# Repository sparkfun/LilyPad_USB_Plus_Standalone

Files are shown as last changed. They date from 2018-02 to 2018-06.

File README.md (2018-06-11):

SparkFun LilyPad USB Plus
========================================

LilyPad USB Plus

[*LilyPad USB Plus (14631)*](https://www.sparkfun.com/products/14631)

This is the LilyPad USB Plus, a sewable electronics microcontroller board controlled by an ATmega32U4 with the Arduino bootloader. 

Repository Contents
-------------------

* **/Documentation** - Data sheets, additional product information
* **/Hardware** - Eagle design files (.brd, .sch)
* **/Production** - Production panel files (.brd)

<b>Note for Linux Users:</b> If you are installing the LilyPad USB Plus in Linux, this document has some specific notes:
<a href="https://github.com/sparkfun/LilyPad_ProtoSnap_Plus/blob/master/Documentation/LinuxInstallation.md">https://github.com/sparkfun/LilyPad_ProtoSnap_Plus/blob/master/Documentation/LinuxInstallation.md</a>.

Documentation
--------------
* **[Library](https://github.com/sparkfun/LilyPad_USB_Plus_Standalone/tree/master/Libraries)** - Arduino library for the LilyPad USB Plus.
* **[Hookup Guide](https://learn.sparkfun.com/tutorials/lilypad-usb-plus-hookup-guide)** - Basic hookup guide for the LilyPad USB Plus.

License Information
-------------------

This product is _**open source**_! 

Please review the LICENSE.md file for license information. 

If you have any questions or concerns on licensing, please contact techsupport@sparkfun.com.

Distributed as-is; no warranty is given.

- Your friends at SparkFun.

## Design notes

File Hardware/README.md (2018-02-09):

SparkFun <PRODUCT NAME> Design Files
=====================================

The .sch and .brd files hare are Eagle CAD schematic and PCB design files from SparkFun Electronics.
A freeware version of Eagle can be found [here](http://www.cadsoftusa.com/download-eagle/freeware/).

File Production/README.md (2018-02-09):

SparkFun <PRODUCT NAME> Production Files
=========================================

These are the production files SparkFun uses for printing PCBs.

License Information
-------------------
This product is open source! 

The hardware is released under [Creative Commons ShareAlike 4.0 International](https://creativecommons.org/licenses/by-sa/4.0/).

Please use, reuse, and modify these files as you see fit. Please maintain attribution to SparkFun Electronics and release anything derivative under the same license.

Distributed as-is; no warranty is given.

- Your friends at SparkFun.

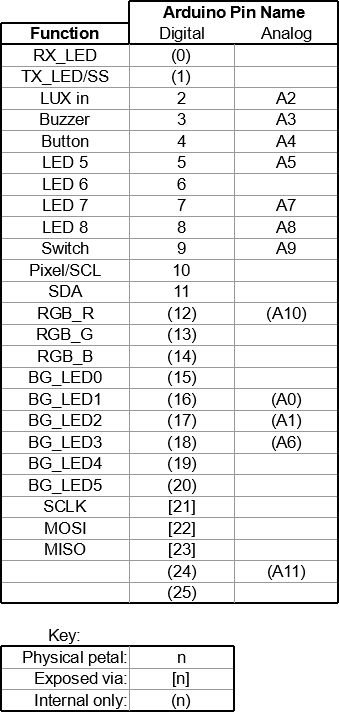
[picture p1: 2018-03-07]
Documentation/Lilypad_USB_Standalone_GPIO_Cheatsheet.png

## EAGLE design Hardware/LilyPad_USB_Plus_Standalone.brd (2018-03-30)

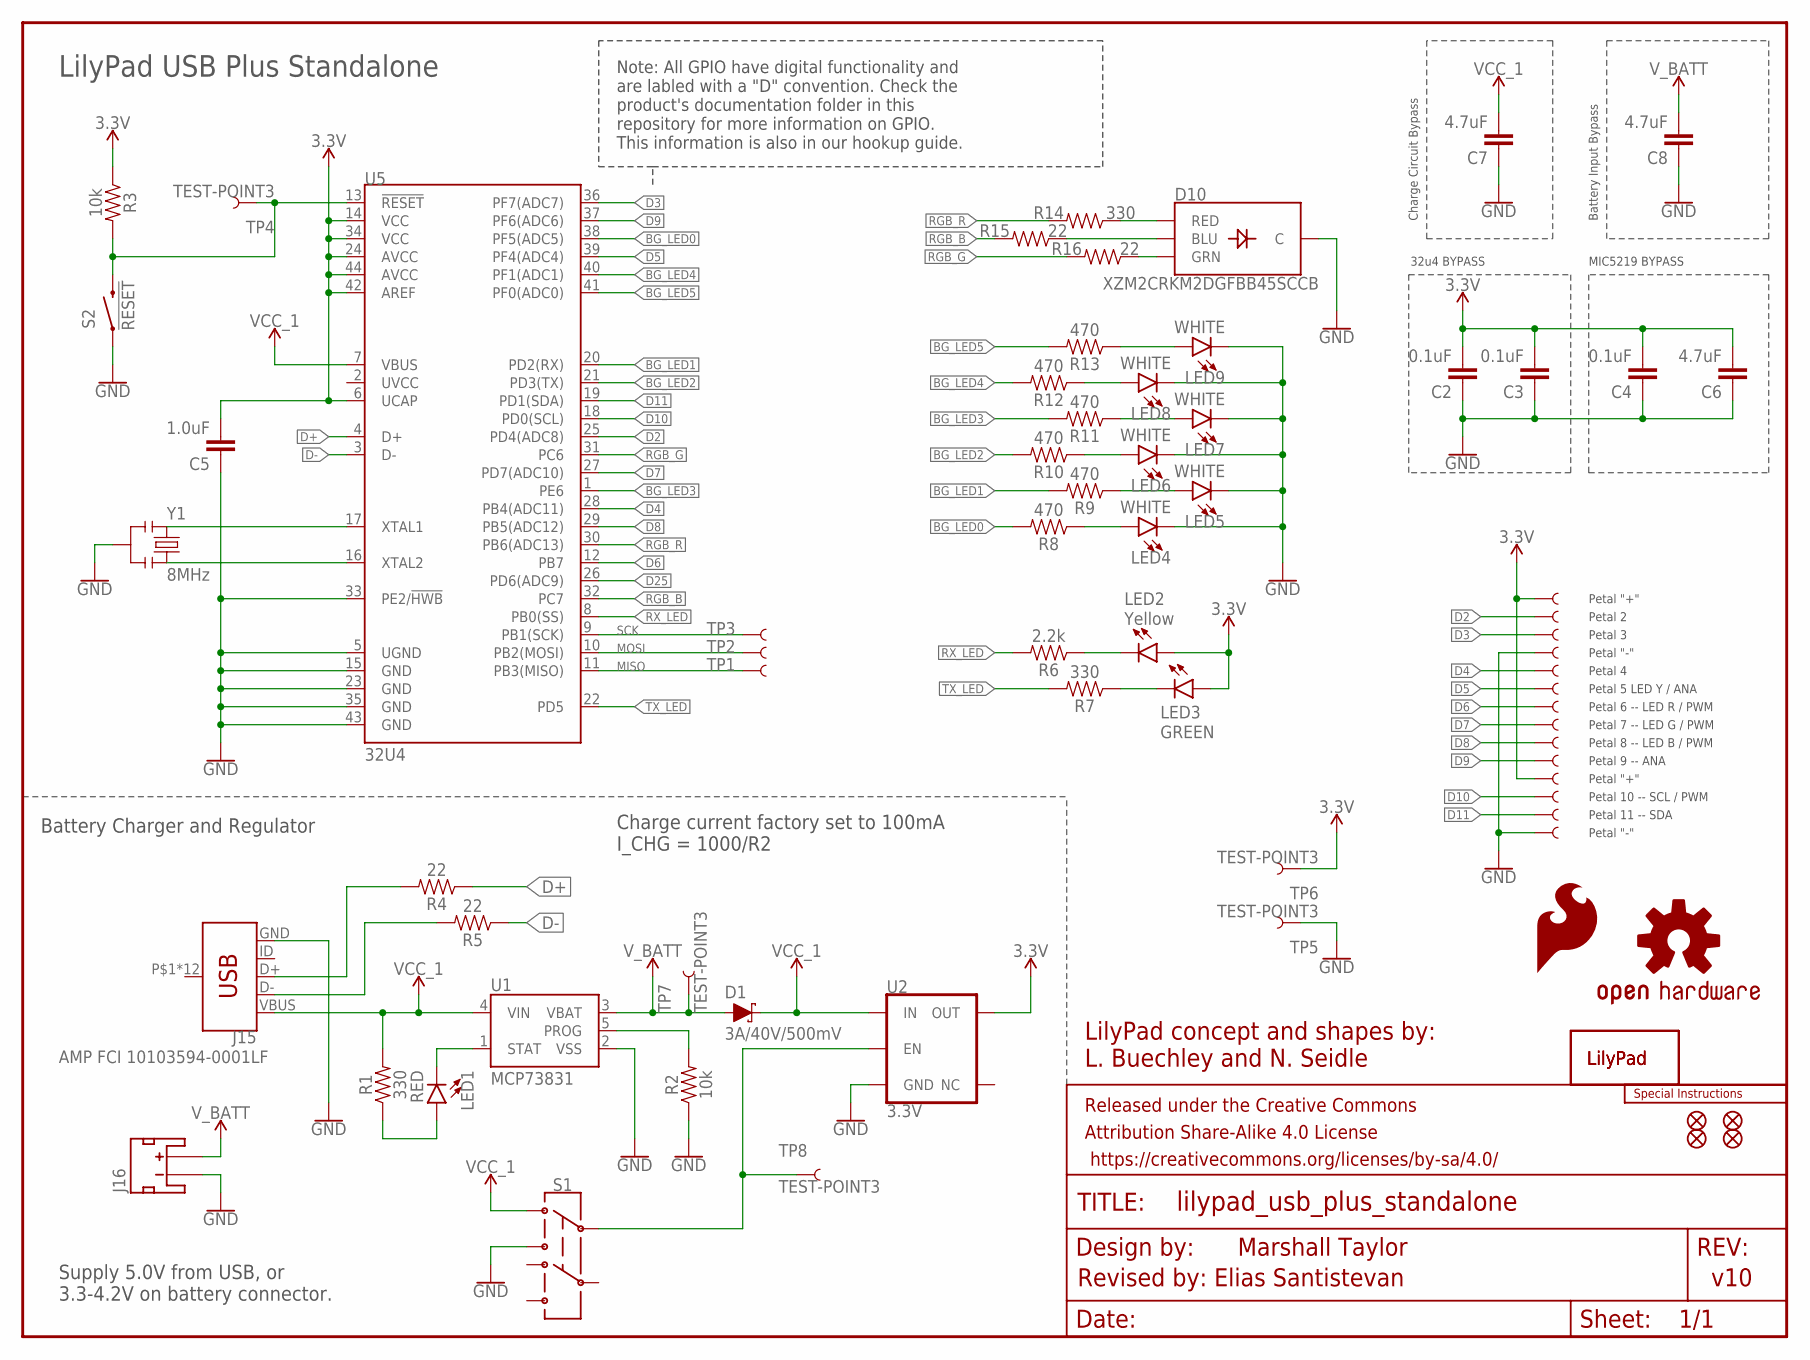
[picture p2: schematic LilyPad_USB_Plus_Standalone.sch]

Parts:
C2, C3, C4: 0.1uF; 0402
C5: 1.0uF; 0402
C6, C7, C8: 4.7uF; 0603
D1: 3A/40V/500mV; SMA-DIODE
D10: XZM2CRKM2DGFBB45SCCB; PLCC4SMDLED
FRAME1: FRAME-LETTER; CREATIVE_COMMONS
J1, J2, J3, J4, J5, J6, J7, J8, J9, J10, J11, J12, J13, J14: SEWTAP_LONG-2SIDE; PETAL-LONG-1-2SIDE
J15: AMP FCI 10103594-0001LF; USB-MICROB-PTH
J16: JST_2MM_MALE; JST-2-SMD
JP1, JP2, JP3, JP4: FIDUCIALUFIDUCIAL; MICRO-FIDUCIAL
LED1: RED; LED-0603
LED2: Yellow; LED-0603
LED3: GREEN; LED-0603
LED4, LED5, LED6, LED7, LED8, LED9: WHITE; LED-0603
LOGO1: SFE_LOGO_FLAME.2_INCH; SFE_LOGO_FLAME_.2
LOGO6: OSHW-LOGOS; OSHW-LOGO-S
R1, R7, R14: 330; 0603
R2, R3: 10k; 0603
R4, R5, R15, R16: 22; 0402
R6: 2.2k; 0603
R8, R9, R10, R11, R12, R13: 470; 0402
S1: SWITCH-DPDT-SMD-AYZ0202; SWITCH_DPDT_SMD_AYZ0202
S2: !RESET; TACTILE_SWITCH_SMD_5.2MM
TP1, TP2, TP3, TP4, TP5, TP6, TP7, TP8: TEST-POINT3; PAD.03X.03
U1: MCP73831; SOT23-5
U2: 3.3V; SOT23-5
U5: 32U4; QFN-44-PAD_1:1-LESS_PASTE
U$1, U$13: LILYLOGO_SHORT; LILYPAD-WEARABLES_LOGO-LILYPAD
U$44: SPECIAL_INSTRUCTIONS-ORDERING; ORDERING_INSTRUCTIONS
Y1: 8MHz; RESONATOR-SMD

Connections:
3.3V: C2.2, C3.2, C4.2, C5.2, C6.2, J1.1, J11.1, LED2.A, LED3.A, R3.1, TP6.P$1, U2.5 (OUT), U5.6 (UCAP), U5.14 (VCC), U5.24 (AVCC), U5.34 (VCC), U5.42 (AREF), U5.44 (AVCC)
BG_LED0: R8.2, U5.38 (PF5(ADC5))
BG_LED1: R9.2, U5.20 (PD2(RX))
BG_LED2: R10.2, U5.21 (PD3(TX))
BG_LED3: R11.2, U5.1 (PE6)
BG_LED4: R12.2, U5.40 (PF1(ADC1))
BG_LED5: R13.2, U5.41 (PF0(ADC0))
D2: J2.1, U5.25 (PD4(ADC8))
D3: J3.1, U5.36 (PF7(ADC7))
D4: J5.1, U5.28 (PB4(ADC11))
D5: J6.1, U5.39 (PF4(ADC4))
D6: J7.1, U5.12 (PB7)
D7: J8.1, U5.27 (PD7(ADC10))
D8: J9.1, U5.29 (PB5(ADC12))
D9: J10.1, U5.37 (PF6(ADC6))
D10: J12.1, U5.18 (PD0(SCL))
D11: J13.1, U5.19 (PD1(SDA))
D25: U5.26 (PD6(ADC9))
D+: R4.1, U5.4 (D+)
D-: R5.1, U5.3 (D-)
GND: C2.1, C3.1, C4.1, C5.1, C6.1, C7.1, C8.1, D10.4 (C), J4.1, J14.1, J15.GND, J16.1 (-), LED4.C, LED5.C, LED6.C, LED7.C, LED8.C, LED9.C, R2.1, S1.3, S2.1, S2.2 (1), TP5.P$1, U1.2 (VSS), U2.2 (GND), U5.5 (UGND), U5.15 (GND), U5.23 (GND), U5.33 (PE2/!HWB), U5.35 (GND), U5.43 (GND), Y1.2
MISO: TP1.P$1, U5.11 (PB3(MISO))
MOSI: TP2.P$1, U5.10 (PB2(MOSI))
unnamed: LED2.C, R6.1
unnamed: S1.2, TP8.P$1, U2.3 (EN)
unnamed: LED1.A, R1.1
unnamed: LED1.C, U1.1 (STAT)
unnamed: U5.17 (XTAL1), Y1.1
unnamed: R2.2, U1.5 (PROG)
unnamed: U5.16 (XTAL2), Y1.3
unnamed: D10.2 (GRN), R16.1
unnamed: LED7.A, R11.1
unnamed: LED6.A, R10.1
unnamed: LED5.A, R9.1
unnamed: LED8.A, R12.1
unnamed: LED9.A, R13.1
unnamed: D10.3 (BLU), R15.1
unnamed: D10.1 (RED), R14.1
unnamed: LED4.A, R8.1
unnamed: J15.D-, R5.2
unnamed: J15.D+, R4.2
unnamed: LED3.C, R7.1
RESET: R3.2, S2.3 (2), S2.4 (2), TP4.P$1, U5.13 (!RESET)
RGB_B: R15.2, U5.32 (PC7)
RGB_G: R16.2, U5.31 (PC6)
RGB_R: R14.2, U5.30 (PB6(ADC13))
RX_LED: R6.2, U5.8 (PB0(SS))
SCK: TP3.P$1, U5.9 (PB1(SCK))
TX_LED: R7.2, U5.22 (PD5)
VCC_1: C7.2, D1.C, J15.VBUS, R1.2, S1.1, U1.4 (VIN), U2.1 (IN), U5.7 (VBUS)
V_BATT: C8.2, D1.A, J16.2 (+), TP7.P$1, U1.3 (VBAT)

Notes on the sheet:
32u4 BYPASS
MIC5219 BYPASS
Marshall Taylor
v10
LilyPad concept and shapes by: L. Buechley and N. Seidle
Charge Circuit Bypass
Battery Input Bypass
Petal 2
Petal 3
Petal 4
Petal 5 LED Y / ANA
Petal 6 -- LED R / PWM
Petal 7 -- LED G / PWM
Petal 8 -- LED B / PWM
Petal 9 -- ANA
Petal 10 -- SCL / PWM
Petal 11 -- SDA
Petal "+"
Petal "-"
LilyPad USB Plus Standalone
Battery Charger and Regulator
Charge current factory set to 100mA I_CHG = 1000/R2
Supply 5.0V from USB, or 3.3-4.2V on battery connector.
Revised by: Elias Santistevan
Note: All GPIO have digital functionality and are labled with a "D" convention. Check the product's documentation folder in this repository for more information on GPIO. This information is also in our hookup guide.

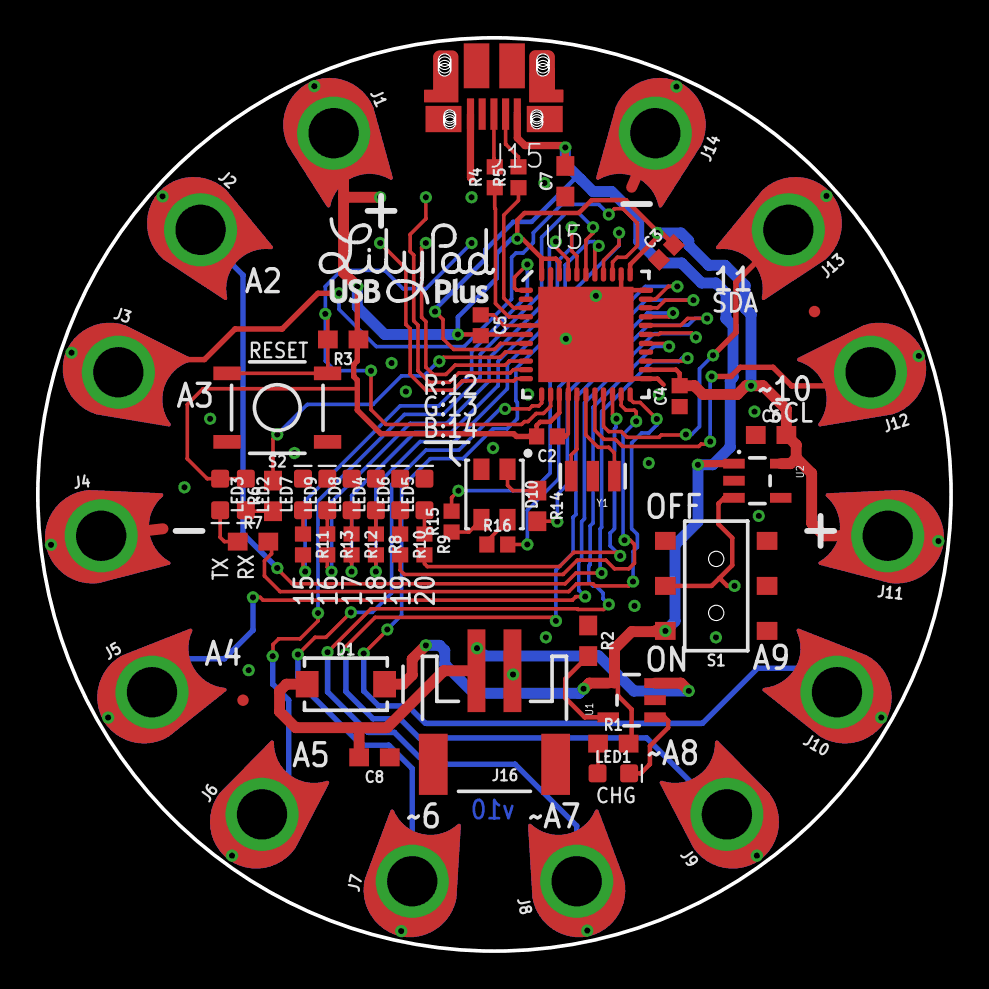
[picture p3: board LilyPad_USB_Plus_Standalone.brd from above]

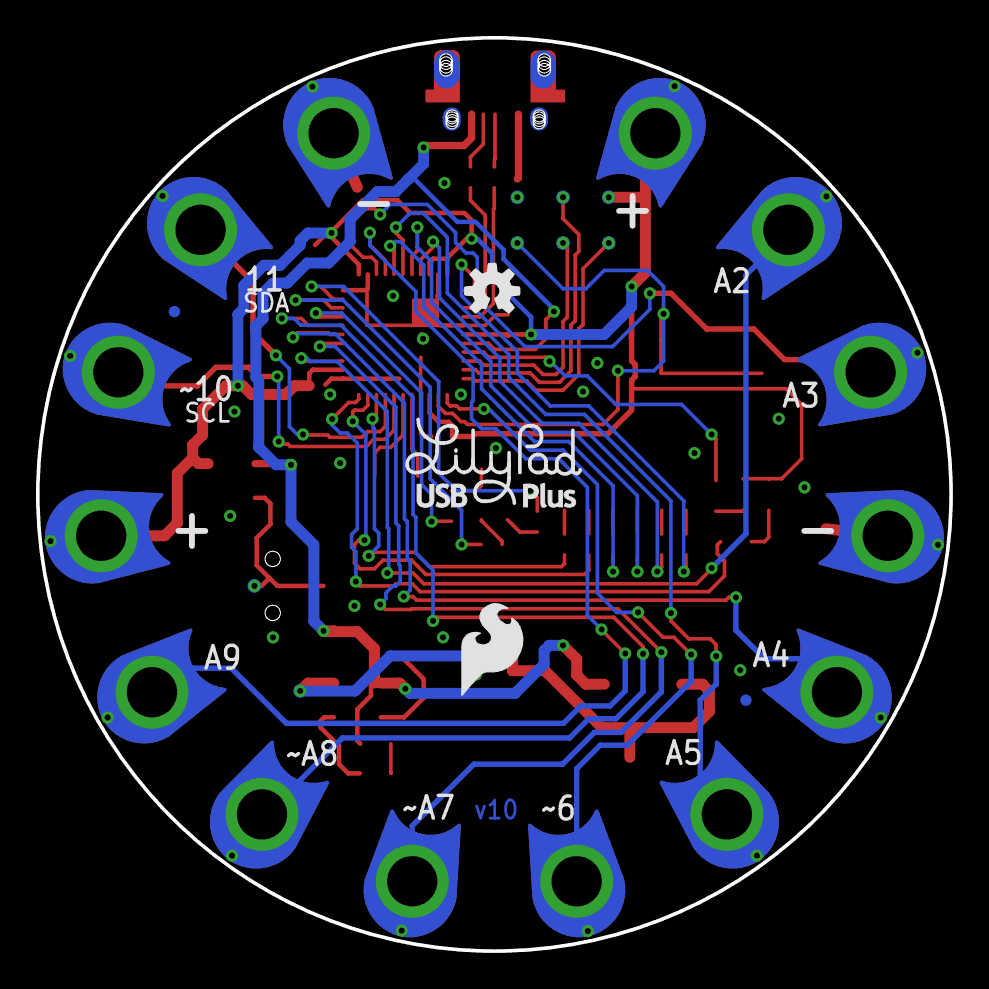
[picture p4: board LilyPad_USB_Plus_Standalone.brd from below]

Board: 2 copper layers, 50.7 x 50.7 mm, 101 parts (13 on the bottom side), 50 nets.

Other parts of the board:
U$3, U$9, U$11, U$15, U$17, U$19, U$21, U$23, U$25, U$27, U$29, U$31, U$33, U$34: PETAL_PAD_OFF
U$7, U$8, U$10, U$12, U$16, U$18, U$20, U$22, U$24, U$26, U$28, U$30, U$32: PETAL_SPACE_OFF

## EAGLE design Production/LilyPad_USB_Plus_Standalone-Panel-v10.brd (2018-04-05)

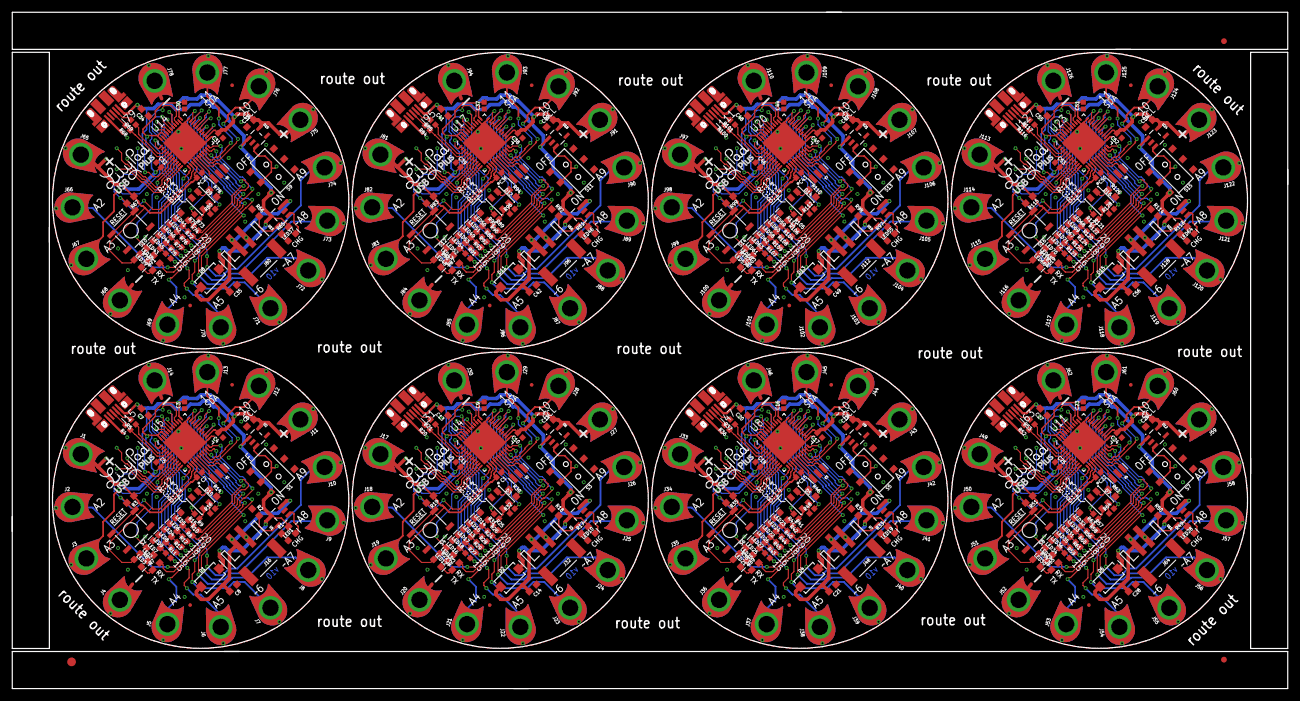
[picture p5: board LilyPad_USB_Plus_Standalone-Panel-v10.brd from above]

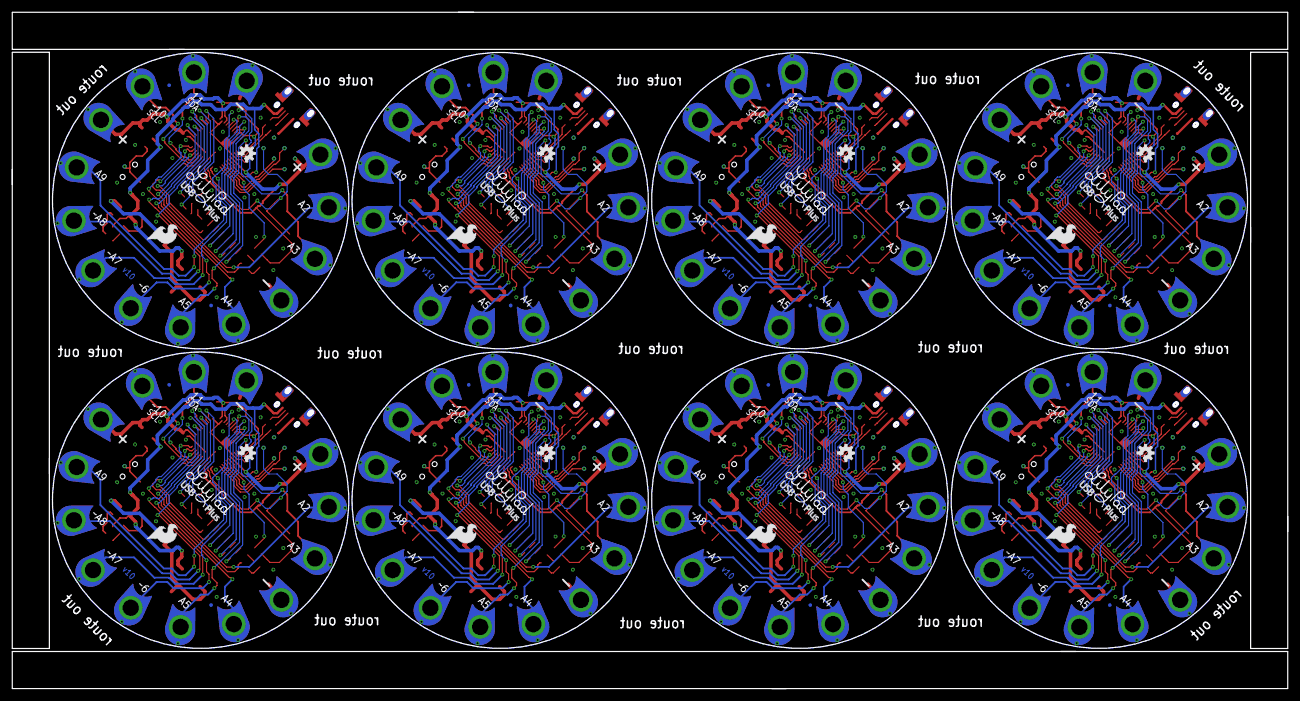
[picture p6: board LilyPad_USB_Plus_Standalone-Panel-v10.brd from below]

Board: 2 copper layers, 218.4 x 115.8 mm, 795 parts (104 on the bottom side), 400 nets.

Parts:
C1, C2, C3, C4, C9, C10, C15, C16, C17, C22, C23, C24, C29, C30, C31, C36, C37, C38, C43, C44, C45, C50, C51, C52: 0.1uF; 0402
C5, C11, C18, C25, C32, C39, C46, C53: 1.0uF; 0402
C6, C7, C8, C12, C13, C14, C19, C20, C21, C26, C27, C28, C33, C34, C35, C40, C41, C42, C47, C48, C49, C54, C55, C56: 4.7uF; 0603
D1, D2, D4, D6, D8, D11, D13, D15: 3A/40V/500mV; SMA-DIODE
D3, D5, D7, D9, D10, D12, D14, D16: XZM2CRKM2DGFBB45SCCB; PLCC4SMDLED
E$1: FIDUCIAL-1.5X3
E$5, E$8: FIDUCIAL-1X2
J1, J2, J3, J4, J5, J6, J7, J8, J9, J10, J11, J12, J13, J14, J17, J18, J19, J20, J21, J22, J23, J24, J25, J26, J27, J28, J29, J30, J33, J34, J35, J36, J37, J38, J39, J40, J41, J42, J43, J44, J45, J46, J49, J50, J51, J52, J53, J54, J55, J56, J57, J58, J59, J60, J61, J62, J65, J66, J67, J68, J69, J70, J71, J72, J73, J74, J75, J76, J77, J78, J81, J82, J83, J84, J85, J86, J87, J88, J89, J90, J91, J92, J93, J94, J97, J98, J99, J100, J101, J102, J103, J104, J105, J106, J107, J108, J109, J110, J113, J114, J115, J116, J117, J118, J119, J120, J121, J122, J123, J124, J125, J126: SEWTAP_LONG-2SIDE; PETAL-LONG-1-2SIDE
J15, J31, J47, J63, J79, J95, J111, J127: AMP FCI 10103594-0001LF; USB-MICROB-PTH
J16, J32, J48, J64, J80, J96, J112, J128: JST-2-SMD
JP1, JP2, JP3, JP4, JP5, JP6, JP7, JP8, JP9, JP10, JP11, JP12, JP13, JP14, JP15, JP16, JP17, JP18, JP19, JP20, JP21, JP22, JP23, JP24, JP25, JP26, JP27, JP28, JP29, JP30, JP31, JP32: FIDUCIALUFIDUCIAL; MICRO-FIDUCIAL
LED1, LED10, LED19, LED28, LED37, LED46, LED55, LED64: RED; LED-0603
LED2, LED11, LED20, LED29, LED38, LED47, LED56, LED65: Yellow; LED-0603
LED3, LED12, LED21, LED30, LED39, LED48, LED57, LED66: GREEN; LED-0603
LED4, LED5, LED6, LED7, LED8, LED9, LED13, LED14, LED15, LED16, LED17, LED18, LED22, LED23, LED24, LED25, LED26, LED27, LED31, LED32, LED33, LED34, LED35, LED36, LED40, LED41, LED42, LED43, LED44, LED45, LED49, LED50, LED51, LED52, LED53, LED54, LED58, LED59, LED60, LED61, LED62, LED63, LED67, LED68, LED69, LED70, LED71, LED72: WHITE; LED-0603
LOGO1, LOGO3, LOGO5, LOGO8, LOGO10, LOGO12, LOGO14, LOGO16: SFE_LOGO_FLAME.2_INCH; SFE_LOGO_FLAME_.2
LOGO2, LOGO4, LOGO6, LOGO7, LOGO9, LOGO11, LOGO13, LOGO15: OSHW-LOGOS; OSHW-LOGO-S
R1, R7, R14, R17, R23, R30, R33, R39, R46, R49, R55, R62, R65, R71, R78, R81, R87, R94, R97, R103, R110, R113, R119, R126: 330; 0603
R2, R3, R18, R19, R34, R35, R50, R51, R66, R67, R82, R83, R98, R99, R114, R115: 10k; 0603
R4, R5, R15, R16, R20, R21, R31, R32, R36, R37, R47, R48, R52, R53, R63, R64, R68, R69, R79, R80, R84, R85, R95, R96, R100, R101, R111, R112, R116, R117, R127, R128: 22; 0402
R6, R22, R38, R54, R70, R86, R102, R118: 2.2k; 0603
R8, R9, R10, R11, R12, R13, R24, R25, R26, R27, R28, R29, R40, R41, R42, R43, R44, R45, R56, R57, R58, R59, R60, R61, R72, R73, R74, R75, R76, R77, R88, R89, R90, R91, R92, R93, R104, R105, R106, R107, R108, R109, R120, R121, R122, R123, R124, R125: 470; 0402
S1, S3, S5, S7, S9, S11, S13, S15: SWITCH_DPDT_SMD_AYZ0202
S2, S4, S6, S8, S10, S12, S14, S16: !RESET; TACTILE_SWITCH_SMD_5.2MM
TP1, TP2, TP3, TP4, TP5, TP6, TP7, TP8, TP9, TP10, TP11, TP12, TP13, TP14, TP15, TP16, TP17, TP18, TP19, TP20, TP21, TP22, TP23, TP24, TP25, TP26, TP27, TP28, TP29, TP30, TP31, TP32, TP33, TP34, TP35, TP36, TP37, TP38, TP39, TP40, TP41, TP42, TP43, TP44, TP45, TP46, TP47, TP48, TP49, TP50, TP51, TP52, TP53, TP54, TP55, TP56, TP57, TP58, TP59, TP60, TP61, TP62, TP63, TP64: TEST-POINT3; PAD.03X.03
U1, U3, U7, U10, U13, U16, U19, U22: MCP73831; SOT23-5
U2, U6, U9, U12, U15, U18, U21, U24: 3.3V; SOT23-5
U4, U5, U8, U11, U14, U17, U20, U23: 32U4; QFN-44-PAD_1:1-LESS_PASTE
U$1, U$13, U$57, U$58, U$86, U$87, U$115, U$116, U$144, U$145, U$173, U$174, U$202, U$203, U$231, U$232: LILYLOGO_SHORT; LILYPAD-WEARABLES_LOGO-LILYPAD
U$2, U$3, U$6, U$9, U$11, U$15, U$17, U$19, U$21, U$23, U$25, U$27, U$29, U$31, U$33, U$34, U$35, U$37, U$39, U$41, U$43, U$45, U$47, U$49, U$51, U$53, U$55, U$56, U$59, U$62, U$64, U$66, U$68, U$70, U$72, U$74, U$76, U$78, U$80, U$82, U$84, U$85, U$88, U$91, U$93, U$95, U$97, U$99, U$101, U$103, U$105, U$107, U$109, U$111, U$113, U$114, U$117, U$120, U$122, U$124, U$126, U$128, U$130, U$132, U$134, U$136, U$138, U$140, U$142, U$143, U$146, U$149, U$151, U$153, U$155, U$157, U$159, U$161, U$163, U$165, U$167, U$169, U$171, U$172, U$175, U$178, U$180, U$182, U$184, U$186, U$188, U$190, U$192, U$194, U$196, U$198, U$200, U$201, U$204, U$207, U$209, U$211, U$213, U$215, U$217, U$219, U$221, U$223, U$225, U$227, U$229, U$230: PETAL_PAD_OFF
U$4, U$5, U$7, U$8, U$10, U$12, U$14, U$16, U$18, U$20, U$22, U$24, U$26, U$28, U$30, U$32, U$36, U$38, U$40, U$42, U$44, U$46, U$48, U$50, U$52, U$54, U$60, U$61, U$63, U$65, U$67, U$69, U$71, U$73, U$75, U$77, U$79, U$81, U$83, U$89, U$90, U$92, U$94, U$96, U$98, U$100, U$102, U$104, U$106, U$108, U$110, U$112, U$118, U$119, U$121, U$123, U$125, U$127, U$129, U$131, U$133, U$135, U$137, U$139, U$141, U$147, U$148, U$150, U$152, U$154, U$156, U$158, U$160, U$162, U$164, U$166, U$168, U$170, U$176, U$177, U$179, U$181, U$183, U$185, U$187, U$189, U$191, U$193, U$195, U$197, U$199, U$205, U$206, U$208, U$210, U$212, U$214, U$216, U$218, U$220, U$222, U$224, U$226, U$228: PETAL_SPACE_OFF
Y1, Y2, Y3, Y4, Y5, Y6, Y7, Y8: 8MHz; RESONATOR-SMD

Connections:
3.3V: C2.2, C3.2, C4.2, C5.2, C6.2, J1.1, J11.1, LED2.A, LED3.A, R3.1, TP6.P$1, U2.5, U5.6, U5.14, U5.24, U5.34, U5.42, U5.44
3.3V1: C1.2, C9.2, C10.2, C11.2, C12.2, J17.1, J27.1, LED11.A, LED12.A, R19.1, TP14.P$1, U4.6, U4.14, U4.24, U4.34, U4.42, U4.44, U6.5
3.3V2: C15.2, C16.2, C17.2, C18.2, C19.2, J33.1, J43.1, LED20.A, LED21.A, R35.1, TP22.P$1, U8.6, U8.14, U8.24, U8.34, U8.42, U8.44, U9.5
3.3V3: C22.2, C23.2, C24.2, C25.2, C26.2, J49.1, J59.1, LED29.A, LED30.A, R51.1, TP30.P$1, U11.6, U11.14, U11.24, U11.34, U11.42, U11.44, U12.5
3.3V4: C29.2, C30.2, C31.2, C32.2, C33.2, J65.1, J75.1, LED38.A, LED39.A, R67.1, TP38.P$1, U14.6, U14.14, U14.24, U14.34, U14.42, U14.44, U15.5
3.3V5: C36.2, C37.2, C38.2, C39.2, C40.2, J81.1, J91.1, LED47.A, LED48.A, R83.1, TP46.P$1, U17.6, U17.14, U17.24, U17.34, U17.42, U17.44, U18.5
3.3V6: C43.2, C44.2, C45.2, C46.2, C47.2, J97.1, J107.1, LED56.A, LED57.A, R99.1, TP54.P$1, U20.6, U20.14, U20.24, U20.34, U20.42, U20.44, U21.5
3.3V7: C50.2, C51.2, C52.2, C53.2, C54.2, J113.1, J123.1, LED65.A, LED66.A, R115.1, TP62.P$1, U23.6, U23.14, U23.24, U23.34, U23.42, U23.44, U24.5
BG_LED0: R8.2, U5.38
BG_LED1: R9.2, U5.20
BG_LED2: R10.2, U5.21
BG_LED3: R11.2, U5.1
BG_LED4: R12.2, U5.40
BG_LED5: R13.2, U5.41
BG_LED6: R24.2, U4.38
BG_LED7: R25.2, U4.20
BG_LED8: R26.2, U4.21
BG_LED9: R27.2, U4.1
BG_LED10: R28.2, U4.40
BG_LED11: R29.2, U4.41
BG_LED12: R40.2, U8.38
BG_LED13: R41.2, U8.20
BG_LED14: R42.2, U8.21
BG_LED15: R43.2, U8.1
BG_LED16: R44.2, U8.40
BG_LED17: R45.2, U8.41
BG_LED18: R56.2, U11.38
BG_LED19: R57.2, U11.20
BG_LED20: R58.2, U11.21
BG_LED21: R59.2, U11.1
BG_LED22: R60.2, U11.40
BG_LED23: R61.2, U11.41
BG_LED24: R72.2, U14.38
BG_LED25: R73.2, U14.20
BG_LED26: R74.2, U14.21
BG_LED27: R75.2, U14.1
BG_LED28: R76.2, U14.40
BG_LED29: R77.2, U14.41
BG_LED30: R88.2, U17.38
BG_LED31: R89.2, U17.20
BG_LED32: R90.2, U17.21
BG_LED33: R91.2, U17.1
BG_LED34: R92.2, U17.40
BG_LED35: R93.2, U17.41
BG_LED36: R104.2, U20.38
BG_LED37: R105.2, U20.20
BG_LED38: R106.2, U20.21
BG_LED39: R107.2, U20.1
BG_LED40: R108.2, U20.40
BG_LED41: R109.2, U20.41
BG_LED42: R120.2, U23.38
BG_LED43: R121.2, U23.20
BG_LED44: R122.2, U23.21
BG_LED45: R123.2, U23.1
BG_LED46: R124.2, U23.40
BG_LED47: R125.2, U23.41
D1: J28.1, U4.18
D2: J2.1, U5.25
D3: J3.1, U5.36
D4: J5.1, U5.28
D5: J6.1, U5.39
D6: J7.1, U5.12
D7: J8.1, U5.27
D8: J9.1, U5.29
D9: J10.1, U5.37
D10: J12.1, U5.18
D11: J13.1, U5.19
D12: J23.1, U4.12
D13: J29.1, U4.19
D14: J18.1, U4.25
D16: J24.1, U4.27
D17: J21.1, U4.28
D18: J25.1, U4.29
D19: J19.1, U4.36
D20: J26.1, U4.37
D21: J22.1, U4.39
D22: J44.1, U8.18
D23: J39.1, U8.12
D24: J45.1, U8.19
D26: J34.1, U8.25
D28: J40.1, U8.27
D29: J37.1, U8.28
D30: J41.1, U8.29
D31: J35.1, U8.36
D32: J42.1, U8.37
D33: J38.1, U8.39
D34: J60.1, U11.18
D35: J55.1, U11.12
D36: J61.1, U11.19
D37: J50.1, U11.25
D39: J56.1, U11.27
D40: J53.1, U11.28
D41: J57.1, U11.29
D42: J51.1, U11.36
D43: J58.1, U11.37
D44: J54.1, U11.39
D45: J76.1, U14.18
D46: J71.1, U14.12
D47: J77.1, U14.19
D48: J66.1, U14.25
D50: J72.1, U14.27
D51: J69.1, U14.28
D52: J73.1, U14.29
D53: J67.1, U14.36
D54: J74.1, U14.37
D55: J70.1, U14.39
D56: J92.1, U17.18
D57: J87.1, U17.12
D58: J93.1, U17.19
D59: J82.1, U17.25
D61: J88.1, U17.27
D62: J85.1, U17.28
D63: J89.1, U17.29
D64: J83.1, U17.36
D65: J90.1, U17.37
D66: J86.1, U17.39
D67: J108.1, U20.18
D68: J103.1, U20.12
D69: J109.1, U20.19
D70: J98.1, U20.25
D72: J104.1, U20.27
D73: J101.1, U20.28
D74: J105.1, U20.29
D75: J99.1, U20.36
D76: J106.1, U20.37
D77: J102.1, U20.39
D78: J124.1, U23.18
D79: J119.1, U23.12
D80: J125.1, U23.19
D81: J114.1, U23.25
D83: J120.1, U23.27
D84: J117.1, U23.28
D85: J121.1, U23.29
D86: J115.1, U23.36
D87: J122.1, U23.37
D88: J118.1, U23.39
D+: R4.1, U5.4
D+1: R20.1, U4.4
D+2: R36.1, U8.4
D+3: R52.1, U11.4
D+4: R68.1, U14.4
D+5: R84.1, U17.4
D+6: R100.1, U20.4
D+7: R116.1, U23.4
D-: R5.1, U5.3
D-1: R21.1, U4.3
D-2: R37.1, U8.3
D-3: R53.1, U11.3
D-4: R69.1, U14.3
D-5: R85.1, U17.3
D-6: R101.1, U20.3
D-7: R117.1, U23.3
GND: C2.1, C3.1, C4.1, C5.1, C6.1, C7.1, C8.1, D10.4, J4.1, J14.1, J15.GND, J16.1, LED4.C, LED5.C, LED6.C, LED7.C, LED8.C, LED9.C, R2.1, S1.3, S2.1, S2.2, TP5.P$1, U1.2, U2.2, U5.5, U5.15, U5.23, U5.33, U5.35, U5.43, Y1.2
GND1: C1.1, C9.1, C10.1, C11.1, C12.1, C13.1, C14.1, D3.4, J20.1, J30.1, J31.GND, J32.1, LED13.C, LED14.C, LED15.C, LED16.C, LED17.C, LED18.C, R18.1, S3.3, S4.1, S4.2, TP13.P$1, U3.2, U4.5, U4.15, U4.23, U4.33, U4.35, U4.43, U6.2, Y2.2
GND2: C15.1, C16.1, C17.1, C18.1, C19.1, C20.1, C21.1, D5.4, J36.1, J46.1, J47.GND, J48.1, LED22.C, LED23.C, LED24.C, LED25.C, LED26.C, LED27.C, R34.1, S5.3, S6.1, S6.2, TP21.P$1, U7.2, U8.5, U8.15, U8.23, U8.33, U8.35, U8.43, U9.2, Y3.2
GND3: C22.1, C23.1, C24.1, C25.1, C26.1, C27.1, C28.1, D7.4, J52.1, J62.1, J63.GND, J64.1, LED31.C, LED32.C, LED33.C, LED34.C, LED35.C, LED36.C, R50.1, S7.3, S8.1, S8.2, TP29.P$1, U10.2, U11.5, U11.15, U11.23, U11.33, U11.35, U11.43, U12.2, Y4.2
GND4: C29.1, C30.1, C31.1, C32.1, C33.1, C34.1, C35.1, D9.4, J68.1, J78.1, J79.GND, J80.1, LED40.C, LED41.C, LED42.C, LED43.C, LED44.C, LED45.C, R66.1, S9.3, S10.1, S10.2, TP37.P$1, U13.2, U14.5, U14.15, U14.23, U14.33, U14.35, U14.43, U15.2, Y5.2
GND5: C36.1, C37.1, C38.1, C39.1, C40.1, C41.1, C42.1, D12.4, J84.1, J94.1, J95.GND, J96.1, LED49.C, LED50.C, LED51.C, LED52.C, LED53.C, LED54.C, R82.1, S11.3, S12.1, S12.2, TP45.P$1, U16.2, U17.5, U17.15, U17.23, U17.33, U17.35, U17.43, U18.2, Y6.2
GND6: C43.1, C44.1, C45.1, C46.1, C47.1, C48.1, C49.1, D14.4, J100.1, J110.1, J111.GND, J112.1, LED58.C, LED59.C, LED60.C, LED61.C, LED62.C, LED63.C, R98.1, S13.3, S14.1, S14.2, TP53.P$1, U19.2, U20.5, U20.15, U20.23, U20.33, U20.35, U20.43, U21.2, Y7.2
GND7: C50.1, C51.1, C52.1, C53.1, C54.1, C55.1, C56.1, D16.4, J116.1, J126.1, J127.GND, J128.1, LED67.C, LED68.C, LED69.C, LED70.C, LED71.C, LED72.C, R114.1, S15.3, S16.1, S16.2, TP61.P$1, U22.2, U23.5, U23.15, U23.23, U23.33, U23.35, U23.43, U24.2, Y8.2
MISO: TP1.P$1, U5.11
MISO1: TP9.P$1, U4.11
MISO2: TP17.P$1, U8.11
MISO3: TP25.P$1, U11.11
MISO4: TP33.P$1, U14.11
MISO5: TP41.P$1, U17.11
MISO6: TP49.P$1, U20.11
MISO7: TP57.P$1, U23.11
MOSI: TP2.P$1, U5.10
MOSI1: TP10.P$1, U4.10
MOSI2: TP18.P$1, U8.10
MOSI3: TP26.P$1, U11.10
MOSI4: TP34.P$1, U14.10
MOSI5: TP42.P$1, U17.10
MOSI6: TP50.P$1, U20.10
MOSI7: TP58.P$1, U23.10
unnamed: LED2.C, R6.1
unnamed: S1.2, TP8.P$1, U2.3
unnamed: LED1.A, R1.1
unnamed: LED1.C, U1.1
unnamed: U5.17, Y1.1
unnamed: R2.2, U1.5
unnamed: U5.16, Y1.3
unnamed: D10.2, R16.1
unnamed: LED7.A, R11.1
unnamed: LED6.A, R10.1
unnamed: LED5.A, R9.1
unnamed: LED8.A, R12.1
unnamed: LED9.A, R13.1
unnamed: D10.3, R15.1
unnamed: D10.1, R14.1
unnamed: S3.2, TP16.P$1, U6.3
unnamed: LED10.A, R17.1
unnamed: LED4.A, R8.1
unnamed: J15.D-, R5.2
unnamed: J15.D+, R4.2
unnamed: LED3.C, R7.1
unnamed: LED10.C, U3.1
unnamed: R18.2, U3.5
unnamed: J31.D-, R21.2
unnamed: J31.D+, R20.2
unnamed: LED11.C, R22.1
unnamed: LED12.C, R23.1
unnamed: U4.17, Y2.1
unnamed: U4.16, Y2.3
unnamed: LED13.A, R24.1
unnamed: LED16.A, R27.1
unnamed: LED15.A, R26.1
unnamed: LED14.A, R25.1
unnamed: LED17.A, R28.1
unnamed: LED18.A, R29.1
unnamed: D3.2, R32.1
unnamed: D3.3, R31.1
unnamed: D3.1, R30.1
unnamed: S5.2, TP24.P$1, U9.3
unnamed: LED19.A, R33.1
unnamed: LED19.C, U7.1
unnamed: R34.2, U7.5
unnamed: J47.D-, R37.2
unnamed: J47.D+, R36.2
unnamed: LED20.C, R38.1
unnamed: LED21.C, R39.1
unnamed: U8.17, Y3.1
unnamed: U8.16, Y3.3
unnamed: LED22.A, R40.1
unnamed: LED25.A, R43.1
unnamed: LED24.A, R42.1
unnamed: LED23.A, R41.1
unnamed: LED26.A, R44.1
unnamed: LED27.A, R45.1
unnamed: D5.2, R48.1
unnamed: D5.3, R47.1
unnamed: D5.1, R46.1
unnamed: S7.2, TP32.P$1, U12.3
unnamed: LED28.A, R49.1
unnamed: LED28.C, U10.1
unnamed: R50.2, U10.5
unnamed: J63.D-, R53.2
unnamed: J63.D+, R52.2
unnamed: LED29.C, R54.1
unnamed: LED30.C, R55.1
unnamed: U11.17, Y4.1
unnamed: U11.16, Y4.3
unnamed: LED31.A, R56.1
unnamed: LED34.A, R59.1
unnamed: LED33.A, R58.1
unnamed: LED32.A, R57.1
unnamed: LED35.A, R60.1
unnamed: LED36.A, R61.1
unnamed: D7.2, R64.1
unnamed: D7.3, R63.1
unnamed: D7.1, R62.1
unnamed: S9.2, TP40.P$1, U15.3
unnamed: LED37.A, R65.1
unnamed: LED37.C, U13.1
unnamed: R66.2, U13.5
unnamed: J79.D-, R69.2
unnamed: J79.D+, R68.2
unnamed: LED38.C, R70.1
unnamed: LED39.C, R71.1
unnamed: U14.17, Y5.1
unnamed: U14.16, Y5.3
unnamed: LED40.A, R72.1
unnamed: LED43.A, R75.1
unnamed: LED42.A, R74.1
unnamed: LED41.A, R73.1
unnamed: LED44.A, R76.1
unnamed: LED45.A, R77.1
unnamed: D9.2, R80.1
unnamed: D9.3, R79.1
unnamed: D9.1, R78.1
unnamed: S11.2, TP48.P$1, U18.3
unnamed: LED46.A, R81.1
unnamed: LED46.C, U16.1
unnamed: R82.2, U16.5
unnamed: J95.D-, R85.2
unnamed: J95.D+, R84.2
unnamed: LED47.C, R86.1
unnamed: LED48.C, R87.1
unnamed: U17.17, Y6.1
unnamed: U17.16, Y6.3
unnamed: LED49.A, R88.1
unnamed: LED52.A, R91.1
unnamed: LED51.A, R90.1
unnamed: LED50.A, R89.1
unnamed: LED53.A, R92.1
unnamed: LED54.A, R93.1
unnamed: D12.2, R96.1
unnamed: D12.3, R95.1
unnamed: D12.1, R94.1
unnamed: S13.2, TP56.P$1, U21.3
unnamed: LED55.A, R97.1
unnamed: LED55.C, U19.1
unnamed: R98.2, U19.5
unnamed: J111.D-, R101.2
unnamed: J111.D+, R100.2
unnamed: LED56.C, R102.1
unnamed: LED57.C, R103.1
unnamed: U20.17, Y7.1
unnamed: U20.16, Y7.3
unnamed: LED58.A, R104.1
unnamed: LED61.A, R107.1
unnamed: LED60.A, R106.1
unnamed: LED59.A, R105.1
unnamed: LED62.A, R108.1
unnamed: LED63.A, R109.1
unnamed: D14.2, R112.1
unnamed: D14.3, R111.1
unnamed: D14.1, R110.1
unnamed: S15.2, TP64.P$1, U24.3
unnamed: LED64.A, R113.1
unnamed: LED64.C, U22.1
unnamed: R114.2, U22.5
unnamed: J127.D-, R117.2
unnamed: J127.D+, R116.2
unnamed: LED65.C, R118.1
unnamed: LED66.C, R119.1
unnamed: U23.17, Y8.1
unnamed: U23.16, Y8.3
unnamed: LED67.A, R120.1
unnamed: LED70.A, R123.1
unnamed: LED69.A, R122.1
unnamed: LED68.A, R121.1
unnamed: LED71.A, R124.1
unnamed: LED72.A, R125.1
unnamed: D16.2, R128.1
unnamed: D16.3, R127.1
unnamed: D16.1, R126.1
RESET: R3.2, S2.3, S2.4, TP4.P$1, U5.13
RESET1: R19.2, S4.3, S4.4, TP12.P$1, U4.13
RESET2: R35.2, S6.3, S6.4, TP20.P$1, U8.13
RESET3: R51.2, S8.3, S8.4, TP28.P$1, U11.13
RESET4: R67.2, S10.3, S10.4, TP36.P$1, U14.13
RESET5: R83.2, S12.3, S12.4, TP44.P$1, U17.13
RESET6: R99.2, S14.3, S14.4, TP52.P$1, U20.13
RESET7: R115.2, S16.3, S16.4, TP60.P$1, U23.13
RGB_B: R15.2, U5.32
RGB_B1: R31.2, U4.32
RGB_B2: R47.2, U8.32
RGB_B3: R63.2, U11.32
RGB_B4: R79.2, U14.32
RGB_B5: R95.2, U17.32
RGB_B6: R111.2, U20.32
RGB_B7: R127.2, U23.32
RGB_G: R16.2, U5.31
RGB_G1: R32.2, U4.31
RGB_G2: R48.2, U8.31
RGB_G3: R64.2, U11.31
RGB_G4: R80.2, U14.31
RGB_G5: R96.2, U17.31
RGB_G6: R112.2, U20.31
RGB_G7: R128.2, U23.31
RGB_R: R14.2, U5.30
RGB_R1: R30.2, U4.30
RGB_R2: R46.2, U8.30
RGB_R3: R62.2, U11.30
RGB_R4: R78.2, U14.30
RGB_R5: R94.2, U17.30
RGB_R6: R110.2, U20.30
RGB_R7: R126.2, U23.30
RX_LED: R6.2, U5.8
RX_LED1: R22.2, U4.8
RX_LED2: R38.2, U8.8
RX_LED3: R54.2, U11.8
RX_LED4: R70.2, U14.8
RX_LED5: R86.2, U17.8
RX_LED6: R102.2, U20.8
RX_LED7: R118.2, U23.8
SCK: TP3.P$1, U5.9
SCK1: TP11.P$1, U4.9
SCK2: TP19.P$1, U8.9
SCK3: TP27.P$1, U11.9
SCK4: TP35.P$1, U14.9
SCK5: TP43.P$1, U17.9
SCK6: TP51.P$1, U20.9
SCK7: TP59.P$1, U23.9
TX_LED: R7.2, U5.22
TX_LED1: R23.2, U4.22
TX_LED2: R39.2, U8.22
TX_LED3: R55.2, U11.22
TX_LED4: R71.2, U14.22
TX_LED5: R87.2, U17.22
TX_LED6: R103.2, U20.22
TX_LED7: R119.2, U23.22
VCC_1: C7.2, D1.C, J15.VBUS, R1.2, S1.1, U1.4, U2.1, U5.7
VCC_2: C13.2, D2.C, J31.VBUS, R17.2, S3.1, U3.4, U4.7, U6.1
VCC_3: C20.2, D4.C, J47.VBUS, R33.2, S5.1, U7.4, U8.7, U9.1
VCC_4: C27.2, D6.C, J63.VBUS, R49.2, S7.1, U10.4, U11.7, U12.1
VCC_5: C34.2, D8.C, J79.VBUS, R65.2, S9.1, U13.4, U14.7, U15.1
VCC_6: C41.2, D11.C, J95.VBUS, R81.2, S11.1, U16.4, U17.7, U18.1
VCC_7: C48.2, D13.C, J111.VBUS, R97.2, S13.1, U19.4, U20.7, U21.1
VCC_8: C55.2, D15.C, J127.VBUS, R113.2, S15.1, U22.4, U23.7, U24.1
V_BATT: C8.2, D1.A, J16.2, TP7.P$1, U1.3
V_BATT1: C14.2, D2.A, J32.2, TP15.P$1, U3.3
V_BATT2: C21.2, D4.A, J48.2, TP23.P$1, U7.3
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

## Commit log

2018-02-12 Cleaned up some things
    Ready for proto review
    [LilyPad_USB_Plus_Standalone.brd, LilyPad_USB_Plus_Standalone.sch]
2018-02-21 Small changes after Review
    [LilyPad_USB_Plus_Standalone.brd]
2018-02-22 Issues found from my double check
    Fiducials on underside placed, Sparkfun name on board changed to flame according to Lilypad design rules.
    [LilyPad_USB_Plus_Standalone.brd, LilyPad_USB_Plus_Standalone.sch]
2018-03-02 Fixed issues from double check
    [LilyPad_USB_Plus_Standalone.sch]
2018-03-07 Updated schematic
    Added a note for the user to clarify net naming convention and a GPIO table to the documentation folder for even further clarification.
    [LilyPad_USB_Plus_Standalone.brd, LilyPad_USB_Plus_Standalone.sch]
2018-03-30 Post designe review changes
    [LilyPad_USB_Plus_Standalone.brd, LilyPad_USB_Plus_Standalone.sch]
2018-03-30 Changes after double check
    [LilyPad_USB_Plus_Standalone.brd, LilyPad_USB_Plus_Standalone.sch]
2018-04-05 created panel v10
    [LilyPad_USB_Plus_Standalone-Panel-v10.brd, LilyPad_USB_Plus_Standalone.sch]
2018-06-08 Deleting empty folders
    Nothing in Enclosure, Firmware, Libraries, Software
2018-06-08 Updating readme with deleted folders
    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

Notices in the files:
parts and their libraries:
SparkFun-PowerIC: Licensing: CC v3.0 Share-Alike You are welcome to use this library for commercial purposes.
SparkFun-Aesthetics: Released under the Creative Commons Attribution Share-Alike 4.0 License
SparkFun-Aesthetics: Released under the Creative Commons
